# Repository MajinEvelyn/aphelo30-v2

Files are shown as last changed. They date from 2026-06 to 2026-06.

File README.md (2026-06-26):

# aphelo30

Pictured with KLP Lame keycaps that I dyed with [Rit Synthetic Dye](https://www.ritdye.com/type/dyemore-for-synthetics/) using [this method](https://blog.zsa.io/how-to-dye-keycaps/). Case printed in Dark Red PLA.

sample1
sample2

## Design Parameters
- Full split
- ZMK powered BLE wireless
- Nice! Nano v2 controlled
- Reversible PCB
- 30 keys in 3x5 configuration
- Choc v1 Switches with hotswap sockets
- No thumb keys
- Middle, ring, and pinky splay

Named for the *Aphelocoma* genus of scrub jay birds, like the original. 

## Overview

This weird combination of features is designed for my hands, which no currently existing boards accommodate. I have RSI issues in both of my thumbs, to the point that even single thumb key layouts don't work for me. Aside from this, the aggressive splay and finger positions were made with Ergopad, and recreated in Ergogen. 

Compared to the first version of this keyboard, I adjusted the splay, overall key position, power and reset button positions, and adjusted the PCB and case to accomodate magnetic USB connectors, which I find very convenient. Additionally, instead of a carrying case using a sliding design, this project uses a much more compact magnetic cover to sandwich between both halves.

In this repo you will find all files related to the design process, including the Ergogen config, KiCAD PCB files, related Gerbers, and case 3d files for printing. 

## Case

There are 4 bosses for heat set inserts on the underside of each half's top case. Press them into each boss with a soldering iron, and use your M2 screws through the holes in the bottom case to screw into the heat set inserts.
There are heat set insert soldering tips available for pretty cheap to make this process easy, but I've heard this is easy enough with typical soldering iron tips.

This case, and PCB is designed with the magnetic USB adapters linked in the BOM, and they sit very flush with the side once assembled. I doubt that other connectors would sit flush in the same way without adjustments to the case design.

The magnets are secured in the cutouts using adhesive, in my case I used B-7000 Clear glue.

mag usb adapter
usb connected

## Carrying Case

This "case" is more of a magnetically attached sandwich cover for the keycaps, and with this arrangement of magnets is very strong. I easily slide into a slot in my camera bag for work.

carry case

## Firmware
ZMK: https://github.com/MajinEvelyn/zmk-config-aphelo30
This is the same firmware as the first version, it is fully compatible with both with no changes.

## BOM

| Name | Count | Notes |
| ---- | ----- | --- |
| PCB | 2 | These are reversible, so either PCB works with either half. |
| Nice! Nano v2 MCU | 2 | |
| Choc v1 Switches | 30 | |
| Choc v1 Hotswap Sockets | 30 | |
| Choc v1 Keycaps | 30 | |
| Power Switch | 2 | |
| Reset Switch | 2 | You can omit these if you are fine with using ZMK reset behavior or shorting RST pins to reflash firmware. |
| 110mah LiPo Battery | 2 | There is plenty of space for other batteries inside the case, but these can sit underneath the nice! nano. |
| Bumpons | 12 | Size is up to your preference. |
| M2(x8mm) Screws | 8 | Countersunk screws are best, they will seat perfectly into the chamfered holes in the bottom case. |
| M2 Heat Set Inserts | 8 | |
| Magnetic USB C adapters | 2 | https://a.co/d/0hXRvKBZ |
| 5 mm x 1 mm Neodynium Magnets | 16 | https://amfmagnets.com/products/neodymium-disc-5-mm-x-1-mm-gold |

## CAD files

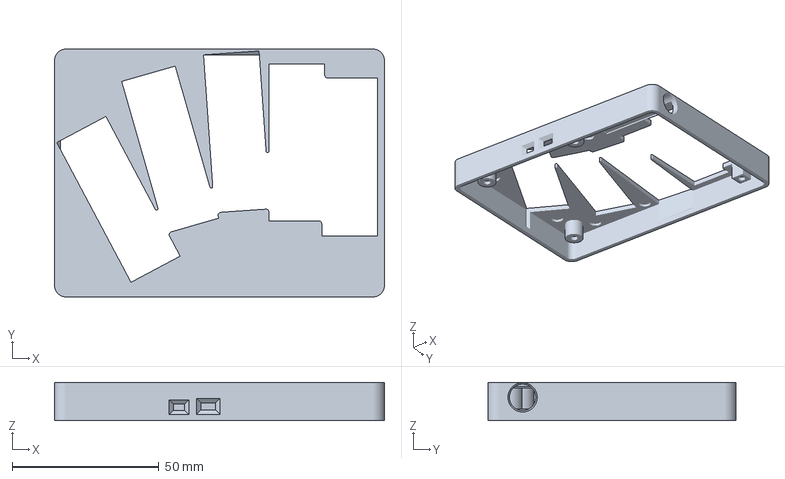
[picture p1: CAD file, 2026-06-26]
case files/aphelo30 v2 case top 1.2.3mf
112.6 x 84.6 x 13.1 mm

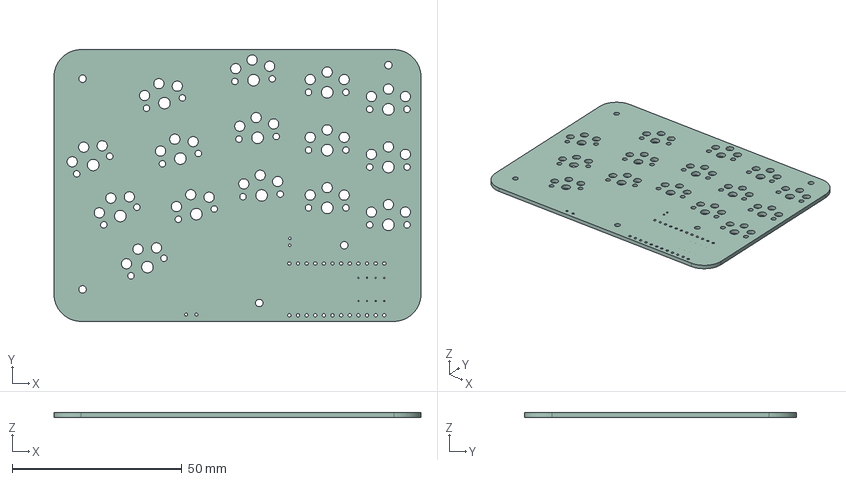
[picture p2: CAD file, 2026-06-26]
pcb files/aphelo30v2.step
108.0 x 80.0 x 1.51 mm

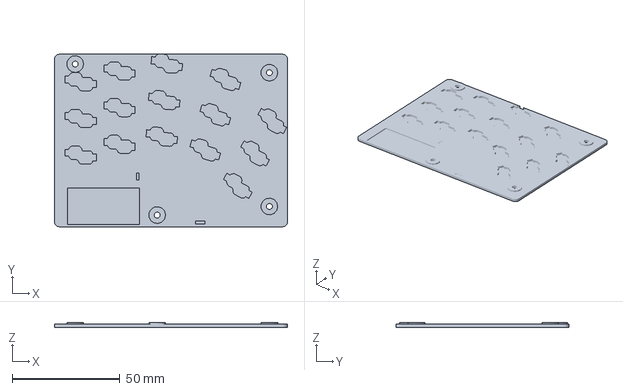
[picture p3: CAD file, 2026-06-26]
case files/aphelo30 v2 case bottom right 1.3.3mf
108.0 x 80.0 x 2.30 mm

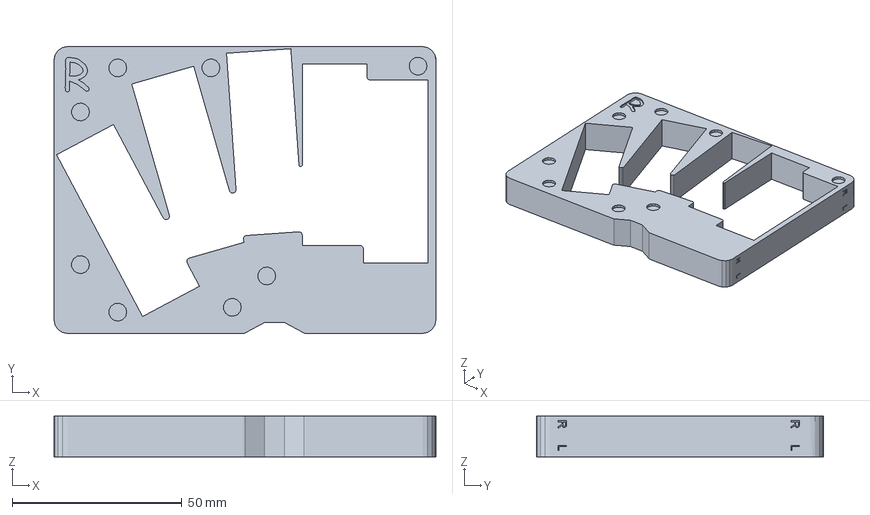
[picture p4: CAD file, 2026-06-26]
case files/aphelo30 v2 magnet cover 1.2.3mf
112.6 x 84.6 x 12.0 mm

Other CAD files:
case files/aphelo30 v2 case bottom 1.2.3mf

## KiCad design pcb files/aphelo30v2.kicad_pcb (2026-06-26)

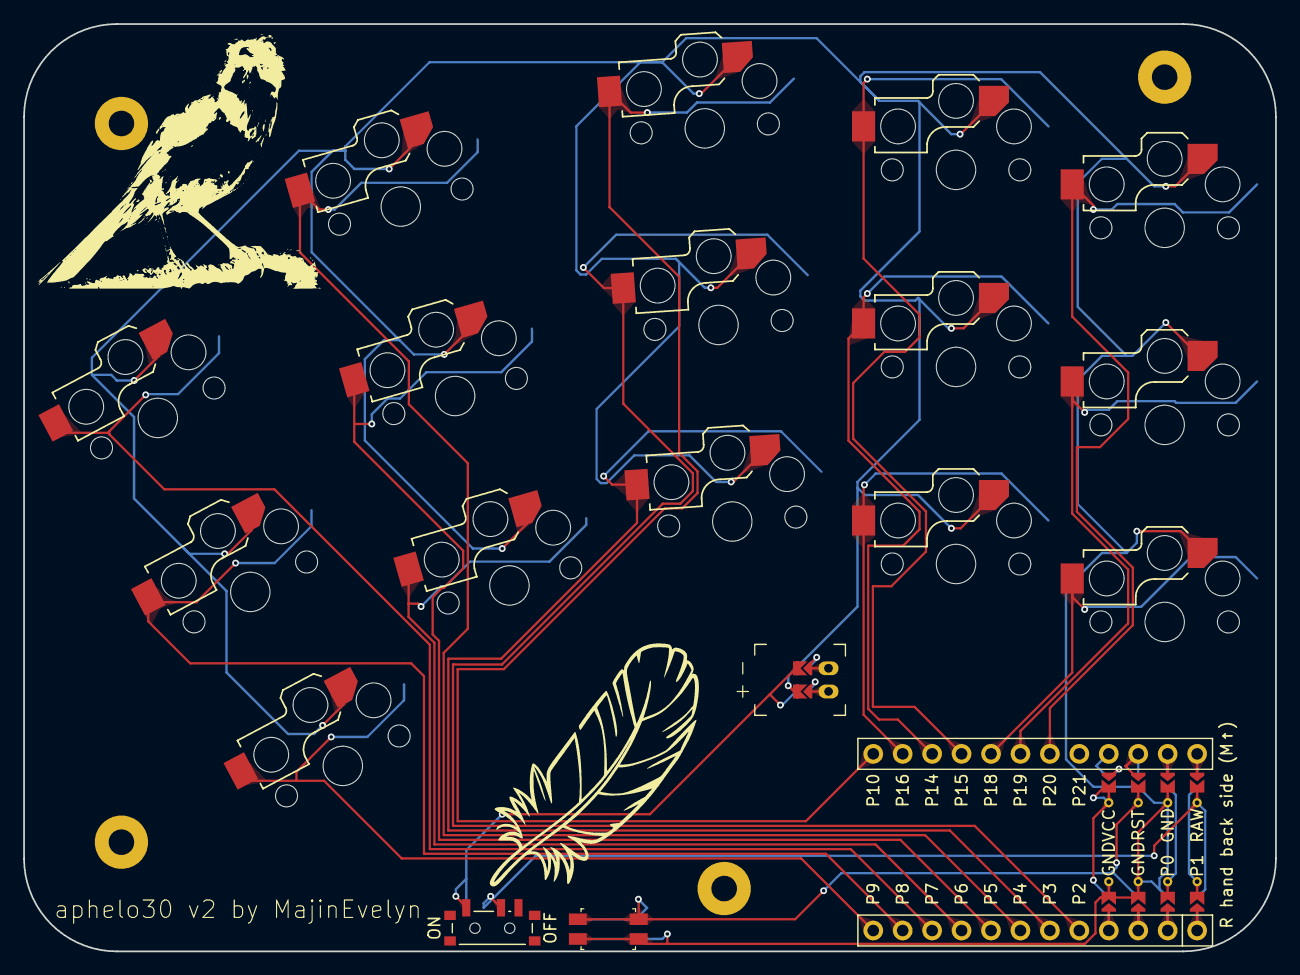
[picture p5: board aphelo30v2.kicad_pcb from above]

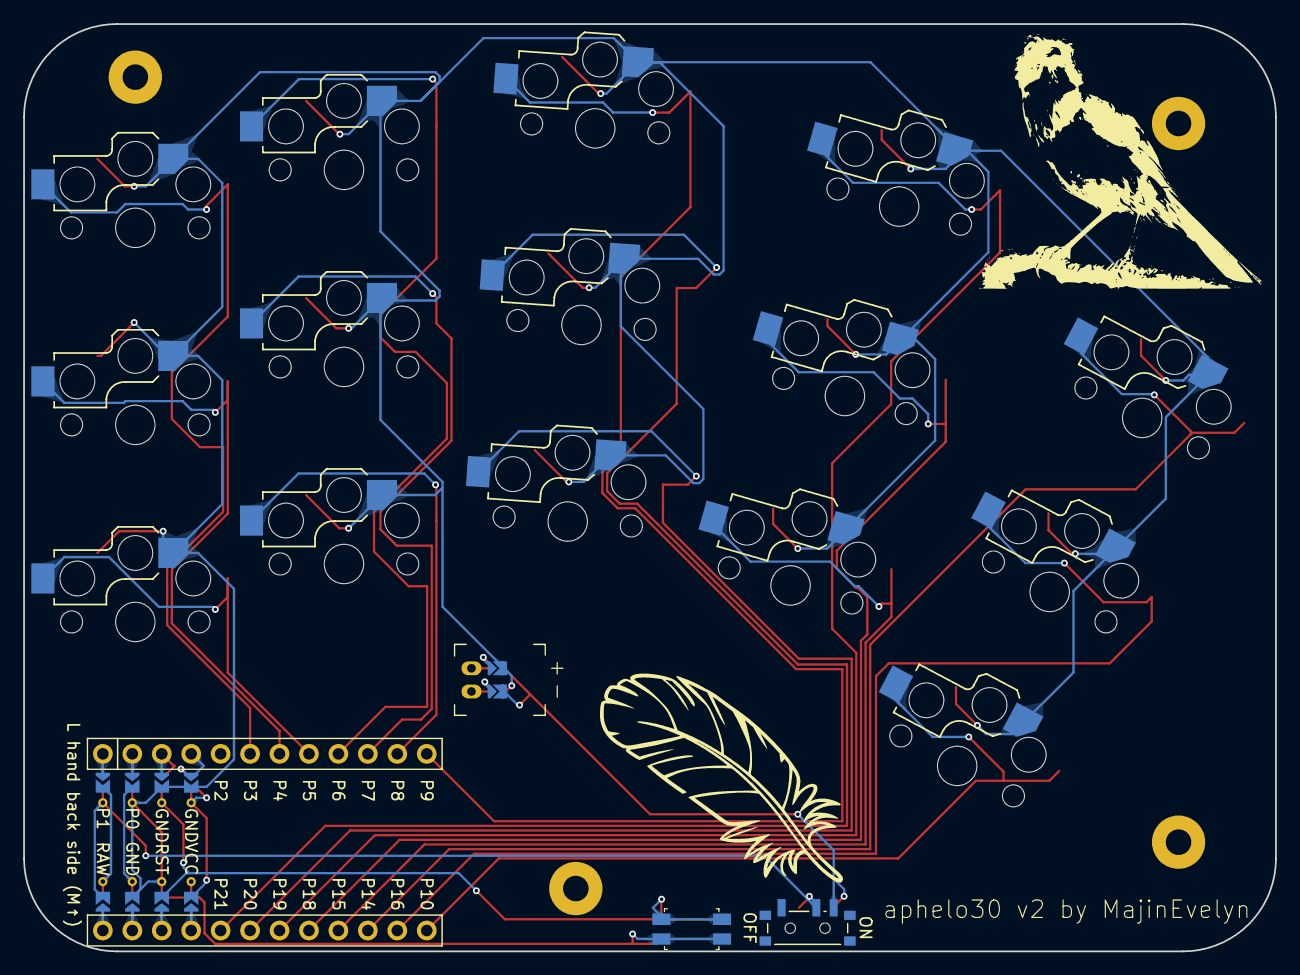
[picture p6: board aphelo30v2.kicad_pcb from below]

Board: 2 copper layers, 108.0 x 80.0 mm, 23 parts (15 on the bottom side), 21 nets.

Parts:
JST1: battery_connector_jst_ph_2
MCU1: mcu_nice_nano
MH1, MH2, MH4, MH5: mounting_hole_npth
PWR1: power_switch_smd_side
RST1: reset_switch_smd_side
S1, S2, S3, S4, S5, S6, S7, S8, S9, S10, S11, S12, S13, S14, S15: switch_choc_v1_v2

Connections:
BAT_P: JST1.1, PWR1.1, PWR1.3
GND: JST1.2, MCU1.103, MCU1.104, MCU1.123, RST1.1, RST1.3, S1.1, S2.1, S3.1, S4.1, S5.1, S6.1, S7.1, S8.1, S9.1, S10.1, S11.1, S12.1, S13.1, S14.1, S15.1
JST1_1: JST1.11, JST1.21, JST1.31
JST1_2: JST1.12, JST1.22, JST1.32
P2: MCU1.5, S8.2
P3: MCU1.6, S7.2
P4: MCU1.7, S6.2
P5: MCU1.8, S5.2
P6: MCU1.9, S4.2
P7: MCU1.10, S3.2
P8: MCU1.11, S2.2
P9: MCU1.12, S1.2
P10: MCU1.13, S9.2
P14: MCU1.15, S11.2
P15: MCU1.16, S12.2
P16: MCU1.14, S10.2
P18: MCU1.17, S13.2
P19: MCU1.18, S14.2
P20: MCU1.19, S15.2
RAW: MCU1.124, PWR1.2
RST: MCU1.122, RST1.2, RST1.4

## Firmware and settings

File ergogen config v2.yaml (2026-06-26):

meta:
  engine: 4.1.0
units:
  px: cx + 2
  py: cy + 2
  $default_width: 18
  $default_height: 17
points:
  zones:
    matrix:
      anchor:
        shift: [100, -100]
      key:
        padding: 1cy
        spread: 1cx
      columns:
        pinky:
          key:
            splay: 28
          rows:
            bottom:
              column_net: P9
            home:
              column_net: P8
            top:
              column_net: P7
        ring:
          key:
            stagger: 7
            splay: -12
            spread: 20
          rows:
            bottom:
              column_net: P6
            home:
              column_net: P5
            top:
              column_net: P4
        middle:
          key:
            stagger: 0
            splay: -12
            spread: 20
          rows:
            bottom:
              column_net: P3
            home:
              column_net: P2
            top:
              column_net: P10
        index:
          key:
            stagger: -5
            splay: -4
            spread: 19
          rows:
            bottom:
              column_net: P16
            home:
              column_net: P14
            top:
              column_net: P15
        inner:
          key:
            stagger: -5
          rows:
            bottom:
              column_net: P18
            home:
              column_net: P19
            top:
              column_net: P20
      rows:
        bottom:
        home:
        top:
outlines:
  bweh:
    - what: rectangle
      size: [cx, cy]
      where: true
  bloc:
    - what: rectangle
      operation: stack
      size: [108, 80]
      adjust.shift: [1.165 sx, -0.95 sy]
      fillet: 8
  bingus:
    - what: polygon
      fillet: 0
      points:
        - ref: matrix_pinky_bottom
          shift: [-0.5cx,-0.5cy]
        - ref: matrix_pinky_top
          shift: [-0.5cx,0.5cy]
        - ref: matrix_pinky_top
          shift: [0.5cx,0.5cy]
        - ref: matrix_ring_top
          shift: [-0.5cx,0]
        - ref: matrix_ring_top
          shift: [-0.5cx,0.5cy]
        - ref: matrix_ring_top
          shift: [0.5cx,0.5cy]
        - ref: matrix_middle_top
          shift: [-0.5cx,0.28cy]
        - ref: matrix_middle_top
          shift: [-0.5cx,0.5cy]
        - ref: matrix_middle_top
          shift: [0.5cx,0.5cy]
        - ref: matrix_middle_top
          shift: [0.5cx,0.25cy]
        - ref: matrix_index_top
          shift: [-0.5cx,0.5cy]
        - ref: matrix_index_top
          shift: [0.5cx,0.5cy]
        - ref: matrix_inner_top
          shift: [-0.5cx,0.5cy]
        - ref: matrix_inner_top
          shift: [0.5cx,0.5cy]
        - ref: matrix_inner_bottom
          shift: [9,-27]
        - ref: matrix_inner_bottom
          shift: [-60,-27]
  combo:
    - name: bloc
    - operation: subtract
      name: bweh
pcbs:
  aphelo30:
    template: kicad8
    outlines:
      main:
        outline: bloc
    footprints:
      choc_hotswap:
        what: ceoloide/switch_choc_v1_v2
        where: true
        params:
          from: GND
          to: "{{column_net}}"
          include_corner_marks: true
          include_keycap: true
          keycap_height: 16.5
          keycap_width: 17.5
          reversible: true
          solder: false
          hotswap: true
          choc_v2_support: false
          outer_pad_width_front: 2.0
          outer_pad_width_back: 2.0
      mcu:
        what: ceoloide/mcu_nice_nano
        where:
          ref: matrix_inner_bottom
        params:
          reversible: true
          only_required_jumpers: true
        adjust:
          shift: [-13.9, -19]
          rotate: -90
      on_off_switch:
        what: ceoloide/power_switch_smd_side
        where: matrix_index_bottom
        params:
          from: BAT_P
          to: RAW
          reversible: true
        adjust:
          shift: [-40, -31.8]
          rotate: -90
      reset_switch:
        what: ceoloide/reset_switch_smd_side
        where: matrix_index_bottom
        params:
          reversible: true
        adjust:
          shift: [-30, -31.5]
          rotate: -180
      battery_connector:
        what: ceoloide/battery_connector_jst_ph_2
        where: matrix_index_bottom
        params:
          reversible: true
        adjust:
          shift: [-11, -10]
          rotate: -90
      m2_screw_mcu1:
        what: ceoloide/mounting_hole_npth
        where: 
          ref: matrix_index_bottom
        adjust:
          shift: [-20,-28]
        params:
          hole_size: 4.6
          hole_drill: 2.2
      m2_screw_bottomleft:
        what: ceoloide/mounting_hole_npth
        where: 
          ref: matrix_index_bottom
        adjust:
          shift: [-72,-24]
        params:
          hole_size: 4.6
          hole_drill: 2.2
      m2_screw_mcu2:
        what: ceoloide/mounting_hole_npth
        where: 
          ref: matrix_index_bottom
        adjust:
          shift: [5,-11]
        params:
          hole_size: 4.6
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

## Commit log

2026-06-26 Revise README for aphelo30 keyboard specifications
    Updated README to reflect new design and features for the aphelo30 keyboard, including images, design parameters, overview, case details, firmware link, and BOM.
2026-06-26 Rename aphelo30 v2 case bottom 1.2.3mf to case files/aphelo30 v2 case bottom 1.2.3mf
    [aphelo30 v2 case bottom 1.2.3mf]
2026-06-26 Rename aphelo30 v2 case bottom right 1.3.3mf to case files/aphelo30 v2 case bottom right 1.3.3mf
    [aphelo30 v2 case bottom right 1.3.3mf]
2026-06-26 Rename aphelo30 v2 case top 1.2.3mf to case files/aphelo30 v2 case top 1.2.3mf
    [aphelo30 v2 case top 1.2.3mf]
2026-06-26 Rename aphelo30 v2 magnet cover 1.2.3mf to case files/aphelo30 v2 magnet cover 1.2.3mf
    [aphelo30 v2 magnet cover 1.2.3mf]
2026-06-26 Rename aphelo30v2.step to pcb files/aphelo30v2.step
    [aphelo30v2.step]
2026-06-26 Update README to simplify design process description
    Removed information about PCB footprint size and cost estimation.
